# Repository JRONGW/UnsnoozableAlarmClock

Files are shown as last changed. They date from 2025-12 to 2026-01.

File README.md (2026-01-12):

# Unsnoozable Alarm Clock

Alarmclockcutouttop
ufocutout
topbottom

- The unsnoozable alarm clock uses a radar sensor to detect if a person is lying on the bed.
- It rings the alarm when alarm clock reaches and the person is present.
- It would not stop until the person leave the bed.

- An improved version is that the pressure pad is added to detect if the person is lying, so the pressure pad is pressed.
- If the pressure pad is pressed or the person is deteted by the radar, the alarm would keep ringing. Otherwise, it would stop ringing (person not detected by radar and the pad is not pressed).

### Instruction for users
- Set the time with the 3 buttons: set, up, and down. 'Set' button would change the set mode from real time hour, real time minute, alarm time hour, alarm time minute, and alarm on or off. In the final version, pressing the 'Set' button can lead you to the real time setting, with another long press to confirm the setting. The continuous hitting of 'Up' or 'Down' button can change the number continuously without re-hitting once a time.

- The pressure pad is separated from the clock, it will detect the pressure on pressure pad and send the status pressed/releaesed to MQTT.

- The pressure pad status can be obtained by the alarm clock and be a condition of the alarm.

- The alarm clock and the pressure pad part are powered by 5v adaptors.

# Iteration 1
iteration1withonlybuzzer

# Iteration 2
iteration2withonlymp3player

# Video of Progress

- Radar Person Detect:


- https://www.youtube.com/watch?v=DdHfjPsBJfA

- Pressue pad:



- https://www.youtube.com/shorts/LzBAYvfItaQ

# Circuit Progress

insideufo6

# Final Iteration
screenshotufo
[https://youtu.be/rHgdz_P1Rgc](https://www.youtube.com/watch?v=OdzALBfLdlw)

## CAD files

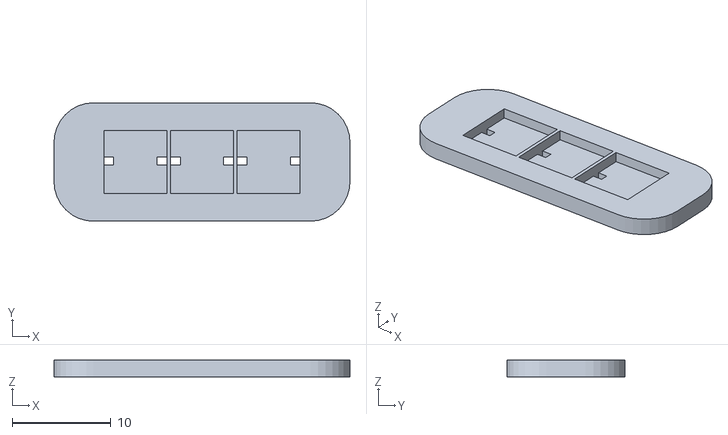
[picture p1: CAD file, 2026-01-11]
Design files/button back.stl
30.0 x 12.0 x 1.70

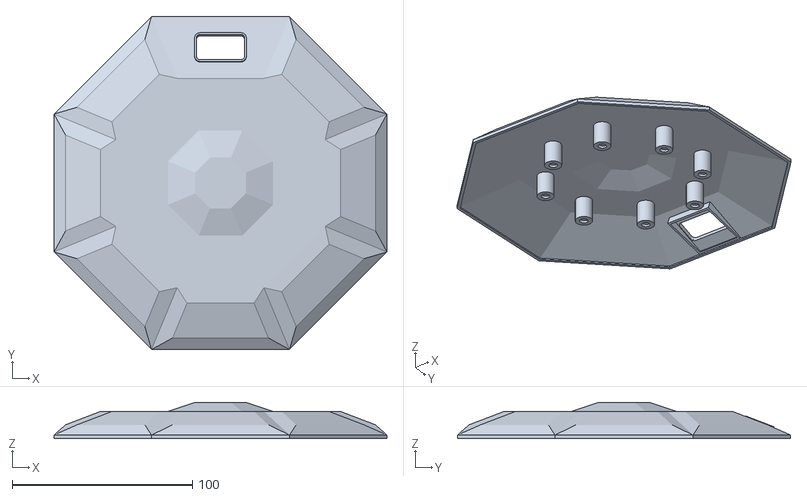
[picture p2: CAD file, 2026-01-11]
Design files/ufo lid.stl
184.8 x 184.8 x 20.1

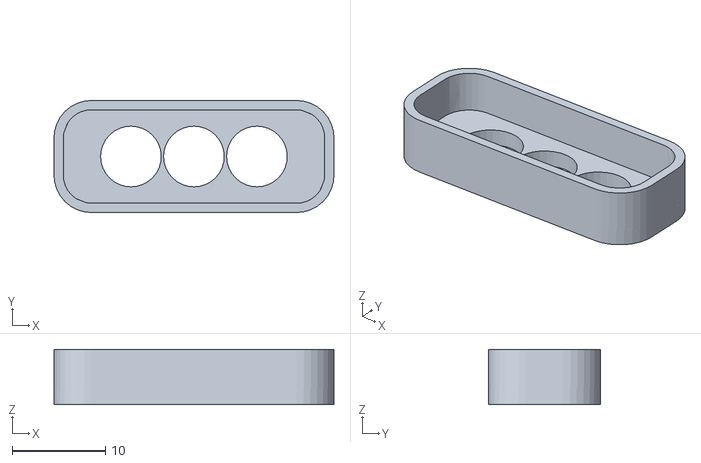
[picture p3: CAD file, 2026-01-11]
Design files/button box.stl
30.0 x 12.0 x 5.90

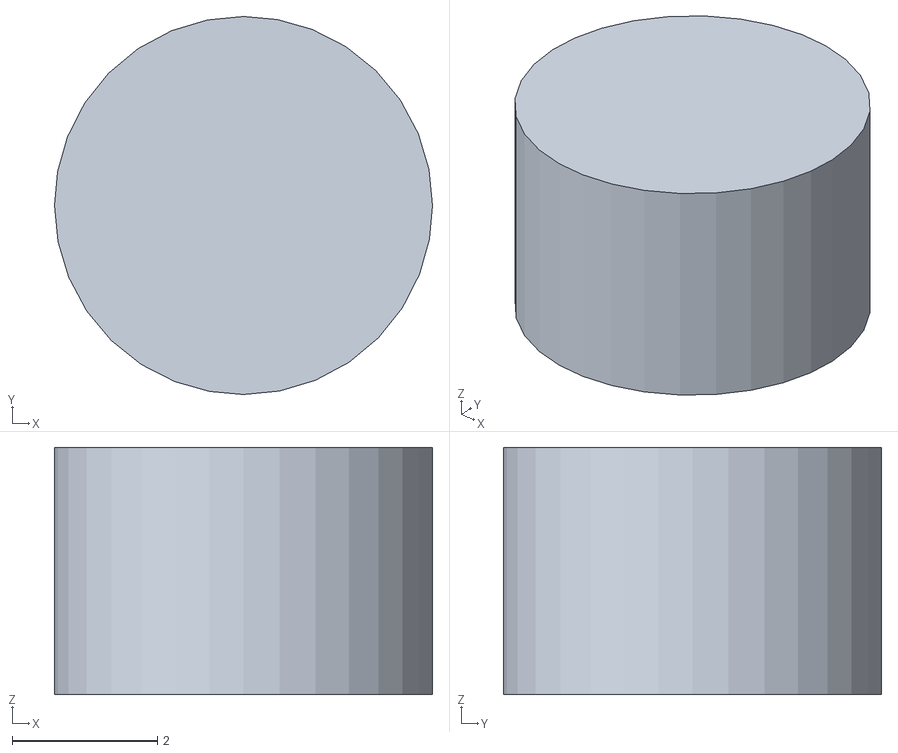
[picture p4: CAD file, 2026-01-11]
Design files/button large.stl
5.20 x 5.20 x 3.40

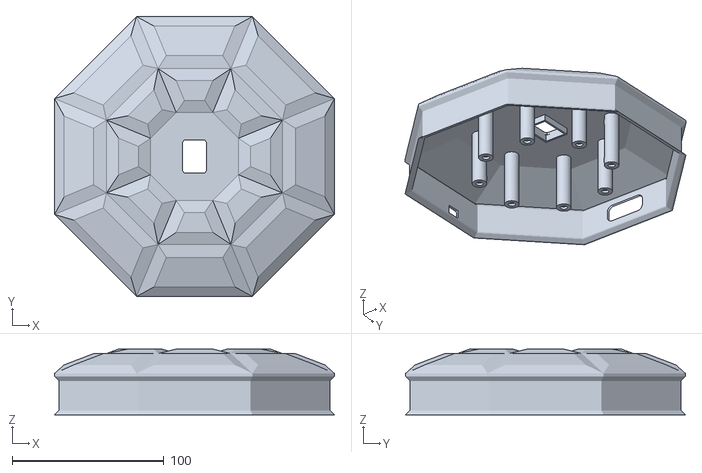
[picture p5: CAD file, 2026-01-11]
Design files/ufo bottom.stl
184.8 x 184.8 x 43.5

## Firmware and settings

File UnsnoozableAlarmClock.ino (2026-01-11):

// On 2026-01-07 at 17:16:10, the setting key was modified. Long press to enter the time modification, and short press to enter the alarm time modification.
// Configured for ESP32 DevKit V1 (WROOM-32)
#ifndef CONFIG_IDF_TARGET
#define CONFIG_IDF_TARGET "esp32"  
#endif

// DS1302 RTC Module:
//   VCC → ESP32 5V (or 3.3V)
//   GND → ESP32 GND
//   CLK → ESP32 GPIO18
//   DAT → ESP32 GPIO23
//   RST → ESP32 GPIO5
// DFPlayer Mini Connections:
//   VCC → ESP32 5V
//   GND → ESP32 GND  
//   TX → ESP32 GPIO2 (MP3_RX_PIN)
//   RX → ESP32 GPIO4 (MP3_TX_PIN)
//   SPK_1 → Speaker Red (+)   
//   SPK_2 → Speaker Black (-) 

#if defined(ESP32)
  #ifdef ESP_IDF_VERSION_MAJOR // IDF 4+
    #if CONFIG_IDF_TARGET_ESP32 // ESP32/PICO-D4
      #define MONITOR_SERIAL Serial
      #define RADAR_SERIAL Serial1
      #define RADAR_RX_PIN 33
      #define RADAR_TX_PIN 32
      MONITOR_SERIAL.print("CONFIG_IxDF_TARGET_ESP32");
   
    #elif CONFIG_IDF_TARGET_ESP32S2
      #define MONITOR_SERIAL Serial
      #define RADAR_SERIAL Serial1
      #define RADAR_RX_PIN 9
      #define RADAR_TX_PIN 8
    #elif CONFIG_IDF_TARGET_ESP32C3
      #define MONITOR_SERIAL Serial
      #define RADAR_SERIAL Serial1
      #define RADAR_RX_PIN 4
      #define RADAR_TX_PIN 5
    #else 
      #error Target CONFIG_IDF_TARGET is not supported
    #endif
  #else // ESP32 Before IDF 4.0
    #define MONITOR_SERIAL Serial
    #define RADAR_SERIAL Serial1
    #define RADAR_RX_PIN 33   //The RX1 pin of the ESP32 is connected to the TX pin of the radar
    #define RADAR_TX_PIN 32   //ESP32's TX1 is connected to the RX of the radar
  #endif
#elif defined(__AVR_ATmega32U4__)
  #define MONITOR_SERIAL Serial
  #define RADAR_SERIAL Serial1
  #define RADAR_RX_PIN 0
  #define RADAR_TX_PIN 1
#endif

#include <Arduino.h>
#include <WiFi.h>
#include <Wire.h>
#include <U8g2lib.h>
#include <ld2410.h>
#include <DFRobotDFPlayerMini.h>
#include <PubSubClient.h>
#include <ThreeWire.h>
#include <RtcDS1302.h>
#include "arduino_secrets.h"

/********* WIFI *********/
const char* ssid = SECRET_SSID;
const char* pass = SECRET_PASS;

/********* MQTT *********/
static const char* MQTT_HOST = "mqtt.cetools.org";
static const int   MQTT_PORT = 1884;  
static const char* MQTT_CLIENTID = "ALARM_CLOCK_JRONG_ESP32";
const char* mqtt_topic_subscribe = "student/CASA0019/Junrong/pressurepad";

/********* MQTT Authentication *********/
static const char* MQTT_USER = MQTT_USERNAME;
static const char* MQTT_PASS = MQTT_PASSWORD;

WiFiClient wifiClient;
PubSubClient mqtt(wifiClient);

// DS1302 RTC pins
#define RTC_CLK_PIN 18
#define RTC_DAT_PIN 23
#define RTC_RST_PIN 5

#define MP3_RX_PIN 4    //The RX2 pin of the ESP32 is connected to the TX pin of the MP3 (pin 3)
#define MP3_TX_PIN 2    //The TX2 pin of the ESP32 is connected to the RX pin (PIN2) of the MP3.

DFRobotDFPlayerMini mp3;
bool mp3Ready = false;

// Initialize DS1302
ThreeWire myWire(RTC_DAT_PIN, RTC_CLK_PIN, RTC_RST_PIN);
RtcDS1302<ThreeWire> rtc(myWire);

// U8g2 Constructor for ELEGOO 0.96" OLED (128x64, I2C) (ROTATE RESET SCL=22 SDA=21)
U8G2_SSD1306_128X64_NONAME_F_HW_I2C u8g2(U8G2_R0, U8X8_PIN_NONE, 22, 21);

// Button pins
#define BTN_SET 25  // Setting key: Switches menu options
#define BTN_UP 26   // Increase button: Click +1 / Long press for combo attack
#define BTN_DOWN 27 // Reduce key: Click -1 / Long press for combo attack

// Buzzer pin
#define BUZZER_PIN 13

// Button debounce
#define DEBOUNCE_DELAY 50
unsigned long lastDebounceTime[3] = {0, 0, 0};
bool lastButtonState[3] = {HIGH, HIGH, HIGH};
bool buttonState[3] = {HIGH, HIGH, HIGH};

// Pressure pad state (received via MQTT)
bool pressurePadPressed = false;
unsigned long lastPressureUpdate = 0;

// Menu states
enum MenuState {
  MENU_CLOCK,
  MENU_SET_HOUR,
  MENU_SET_MINUTE,
  MENU_SET_ALARM_HOUR,
  MENU_SET_ALARM_MINUTE,
  MENU_ALARM_ENABLE
};

MenuState currentMenu = MENU_CLOCK;

// Time variables
int currentHour = 12;
int currentMinute = 0;
int currentSecond = 0;
unsigned long lastTimeUpdate = 0;

// Alarm variables
int alarmHour = 7;
int alarmMinute = 0;
bool alarmEnabled = false;
bool alarmTriggered = false;
bool alarmRinging = false;

ld2410 radar;
uint32_t lastReading = 0;
bool radarConnected = false;
bool presenceDetected = false;
int targetDistance = 0;

bool displayConnected = false;
bool rtcConnected = false;
bool wifiConnected = false;
bool mqttConnected = false;

unsigned long lastMQTTAttempt = 0;
const unsigned long MQTT_RETRY_INTERVAL = 5000;

bool setting_mode = false;      //Set mode flag (true = enter settings / false = normal display)

// Button shake reduction + combo parameters (industrial-grade configuration, no need for modification)
const int DEBOUNCE_TIME = 20;   // Shake-off time: 20 ms
const int LONG_PRESS_TIME = 500;// Long press to determine time: 500ms
const int REPEAT_INTERVAL = 200;// The interval between consecutive attacks is 200 milliseconds.


// 将设置参数写入DS1302，立即生效
void saveParamToRtc() {
  RtcDateTime initTime(2026, 1, 3, 9, 35, 0); // Year, month, day, hour, minute, second
  rtc.SetDateTime(initTime);
}

// ==================== MQTT Callback ====================
void mqttCallback(char* topic, byte* payload, unsigned int length) {
  String message = "";
  for (int i = 0; i < length; i++) {
    message += (char)payload[i];
  }
  
  MONITOR_SERIAL.print("📩 MQTT [");
  MONITOR_SERIAL.print(topic);
  MONITOR_SERIAL.print("]: ");
  MONITOR_SERIAL.println(message);
  
  // Check if it's from the pressure pad topic
  if (String(topic) == mqtt_topic_subscribe) {
    if (message == "pressed") {
      pressurePadPressed = true;
      lastPressureUpdate = millis();
      MONITOR_SERIAL.println("✓ Pressure pad: PRESSED");
    } else if (message == "released") {
      pressurePadPressed = false;
      lastPressureUpdate = millis();
      MONITOR_SERIAL.println("✓ Pressure pad: RELEASED");
    }
  }
}

// ==================== WiFi Setup ====================
void connectWiFi() {
  if (WiFi.status() == WL_CONNECTED) return;
  
  MONITOR_SERIAL.print("Connecting to WiFi: ");
  MONITOR_SERIAL.println(ssid);
  
  u8g2.clearBuffer();
  u8g2.setFont(u8g2_font_6x10_tr);

  u8g2.setFont(u8g2_font_unifont_t_symbols); 
  u8g2.setFont(u8g2_font_open_iconic_all_1x_t); 
  u8g2.setFont(u8g2_font_7x13_t_symbols); 
  u8g2.drawStr(0, 15, "Connecting WiFi...");
  u8g2.sendBuffer();
  
  WiFi.begin(ssid, pass);
  
  int attempts = 0;
  while (WiFi.status() != WL_CONNECTED && attempts < 40) {
    delay(500);
    MONITOR_SERIAL.print(".");
    attempts++;
  }
  
  if (WiFi.status() == WL_CONNECTED) {
    wifiConnected = true;
    MONITOR_SERIAL.println("\n✓ WiFi Connected!");
    MONITOR_SERIAL.print("IP: ");
    MONITOR_SERIAL.println(WiFi.localIP());
    
    u8g2.clearBuffer();
    u8g2.setFont(u8g2_font_6x10_tr);
    u8g2.drawStr(0, 15, "WiFi Connected!");
    u8g2.sendBuffer();
    delay(2000);
  } else {
    wifiConnected = false;
    MONITOR_SERIAL.println("\n✗ WiFi Failed!");
    u8g2.clearBuffer();
    u8g2.setFont(u8g2_font_6x10_tr);
    u8g2.drawStr(0, 15, "WiFi Failed!");
    u8g2.sendBuffer();
    delay(2000);
  }
}

// ==================== MQTT Setup ====================
void ensureMQTT() {
  if (mqtt.connected()) {
    mqttConnected = true;
    return;
  }
  
  if (millis() - lastMQTTAttempt < MQTT_RETRY_INTERVAL) return;
  
  lastMQTTAttempt = millis();
  
  MONITOR_SERIAL.print("MQTT connect ");
  MONITOR_SERIAL.print(MQTT_HOST);
  MONITOR_SERIAL.print(":");
  MONITOR_SERIAL.println(MQTT_PORT);
  
  u8g2.clearBuffer();
  u8g2.setFont(u8g2_font_6x10_tr);
  u8g2.drawStr(0, 15, "Connecting MQTT...");
  u8g2.sendBuffer();
  
  bool ok = mqtt.connect(MQTT_CLIENTID, MQTT_USER, MQTT_PASS);
  
  if (ok) {
    mqttConnected = true;
    MONITOR_SERIAL.println("✓ MQTT Connected!");
    
    // Subscribe to pressure pad topic
    mqtt.subscribe(mqtt_topic_subscribe);
    MONITOR_SERIAL.print("Subscribed to: ");
    MONITOR_SERIAL.println(mqtt_topic_subscribe);
    
    u8g2.clearBuffer();
    u8g2.setFont(u8g2_font_6x10_tr);
    u8g2.drawStr(0, 15, "MQTT Connected!");
    u8g2.sendBuffer();
    delay(1000);
    
  } else {
    mqttConnected = false;
    MONITOR_SERIAL.print("MQTT fail rc=");
    MONITOR_SERIAL.println(mqtt.state());
    
    u8g2.clearBuffer();
    u8g2.setFont(u8g2_font_6x10_tr);
    u8g2.drawStr(0, 15, "MQTT Failed!");
    u8g2.sendBuffer();
  }
}
// 补零函数（格式化时间）
String formatNum(int num) {
  return num < 10 ? "0" + String(num) : String(num);
}

void setup(void)
{
  MONITOR_SERIAL.begin(115200);
  delay(1000);
  MONITOR_SERIAL.println("\n--- Un-Snoozeable Alarm Clock ---");
  
  // Setup buttons
  pinMode(BTN_SET, INPUT_PULLUP);
  pinMode(BTN_UP, INPUT_PULLUP);
  pinMode(BTN_DOWN, INPUT_PULLUP);

  // Setup buzzer
  pinMode(BUZZER_PIN, OUTPUT);
  digitalWrite(BUZZER_PIN, LOW);

  MONITOR_SERIAL.println("Initializing I2C for OLED...");
  Wire.begin(21, 22); // I2C initialization: SDA connected to 21, SCL connected to 22. For the other ESP32 I2C initialization, Wire.begin(18, 19);
  Wire.setClock(400000); // Increase the I2C speed to 400kHz (default is 100kHz)
  
  MONITOR_SERIAL.println("Initializing OLED Display...");

  // Initialize display
  u8g2.begin();
  u8g2.enableUTF8Print();
  displayConnected = true;
  
  MONITOR_SERIAL.println("Display initialized!");
  
  // Welcome screen
  u8g2.clearBuffer();
  u8g2.setFont(u8g2_font_ncenB14_tr);
  u8g2.drawStr(0, 20, "HELLO!");
  u8g2.setFont(u8g2_font_6x10_tr);
  u8g2.drawStr(0, 35, "Alarm Clock");
  u8g2.drawStr(0, 50, "Init systems...");
  u8g2.sendBuffer();
  
  delay(1000);

  // Initialize WiFi
  connectWiFi();
  
  // Initialize MQTT
  if (wifiConnected) {
    mqtt.setServer(MQTT_HOST, MQTT_PORT);
    mqtt.setCallback(mqttCallback);
    ensureMQTT();
  }

  // Initialize DS1302 RTC
  MONITOR_SERIAL.println("Initializing RTC Module...");
  MONITOR_SERIAL.print("  CLK: GPIO");
  MONITOR_SERIAL.println(RTC_CLK_PIN);
  MONITOR_SERIAL.print("  DAT: GPIO");
  MONITOR_SERIAL.println(RTC_DAT_PIN);
  MONITOR_SERIAL.print("  RST: GPIO");
  MONITOR_SERIAL.println(RTC_RST_PIN);
  
  rtc.Begin();
   // First use: Set the initial time
  RtcDateTime initTime(2026, 1, 3, 9, 35, 0); 
  if (!rtc.IsDateTimeValid()) {
    rtc.SetDateTime(initTime);
  	Serial.println("MH-DS1302 V2：Initialization time successful");
  } else {
     Serial.println("MH-DS1302 V2：The time is valid and does not need to be reset.");
  }

  if (!rtc.GetIsRunning()) {
    MONITOR_SERIAL.println("RTC was not running, starting now");
    rtc.SetIsRunning(true);
  }

  RtcDateTime now = rtc.GetDateTime();
  now = rtc.GetDateTime(); // Second reading, stable V2 version data
  rtcConnected = true;
  // Format the time
  static String date = String(now.Year()) + "/" + formatNum(now.Month()) + "/" + formatNum(now.Day());
  static String time = formatNum(now.Hour()) + ":" + formatNum(now.Minute()) + ":" + formatNum(now.Second());

  currentHour = now.Hour();
  currentMinute = now.Minute();
  currentSecond = now.Second();
  MONITOR_SERIAL.print(date);
  MONITOR_SERIAL.print(" Current RTC time: ");
  MONITOR_SERIAL.print(time);
  MONITOR_SERIAL.println(" ");  
  u8g2.clearBuffer();
  u8g2.setFont(u8g2_font_ncenB10_tr);
  u8g2.drawStr(0, 15, "Clock on!");
  u8g2.setFont(u8g2_font_6x10_tr);
  char timeStr[20];
  sprintf(timeStr, "Time: %02d:%02d:%02d", currentHour, currentMinute, currentSecond);
  u8g2.drawStr(0, 35, timeStr);
  u8g2.sendBuffer();
  delay(2000);

  // ---------- Initialize Radar ----------
  u8g2.clearBuffer();
  u8g2.setFont(u8g2_font_6x10_tr);
  u8g2.drawStr(0, 15, "Starting Radar...");
  u8g2.sendBuffer();

#if defined(ESP32)
  MONITOR_SERIAL.println("Initializing Radar UART...");
  MONITOR_SERIAL.printf("RADAR_RX_PIN=%d,RADAR_TX_PIN=%d  ", RADAR_RX_PIN, RADAR_TX_PIN);
  RADAR_SERIAL.begin(256000, SERIAL_8N1, RADAR_RX_PIN, RADAR_TX_PIN);
#elif defined(__AVR_ATmega32U4__)
  RADAR_SERIAL.begin(256000);
#endif

  delay(500);

  bool ok = false;
  unsigned long start = millis();

  while (millis() - start < 3000) {
    if (!ok) {
      MONITOR_SERIAL.println("Calling radar.begin()...");
      ok = radar.begin(RADAR_SERIAL);
    }

    radar.read();

    if (radar.isConnected()) {
      ok = true;
      break;
    }

    delay(100);
  }

  radarConnected = ok;

  u8g2.clearBuffer();
  u8g2.setFont(u8g2_font_6x10_tr);

  if (radarConnected) {
    MONITOR_SERIAL.println(F("Radar: OK"));

    u8g2.setFont(u8g2_font_ncenB10_tr);
    u8g2.drawStr(0, 15, "RADAR OK!");
    u8g2.setFont(u8g2_font_6x10_tr);

    char fwStr[20];
    sprintf(fwStr, "FW v%d.%d.%02X",
            radar.firmware_major_version,
            radar.firmware_minor_version,
            radar.firmware_bugfix_version);
    u8g2.drawStr(0, 30, fwStr);
  } else {
    MONITOR_SERIAL.println(F("Radar: FAILED"));

    u8g2.drawStr(0, 15, "Radar Error");
    u8g2.drawStr(0, 30, "Check wiring / reboot");
  }

  u8g2.sendBuffer();
  delay(2000);

  // --- Initialize MP3 player ---
  MONITOR_SERIAL.println("Initializing MP3 player...");
  MONITOR_SERIAL.print("  RX: GPIO");
  MONITOR_SERIAL.println(MP3_RX_PIN);
  MONITOR_SERIAL.print("  TX: GPIO");
  MONITOR_SERIAL.println(MP3_TX_PIN);

  Serial2.begin(9600, SERIAL_8N1, MP3_RX_PIN, MP3_TX_PIN);
  delay(2000);

  MONITOR_SERIAL.println("Attempting connection...");

  if (mp3.begin(Serial2)) {
    mp3Ready = true;
    MONITOR_SERIAL.println("✓ MP3 player OK");
    
    delay(500);
    mp3.volume(15);
    delay(500);
    
    // Test play
    MONITOR_SERIAL.println("Testing playback...");
    mp3.play(1);
    delay(3000);
    mp3.stop();
    
  } else {
    mp3Ready = false;
    MONITOR_SERIAL.println("❌ MP3 player NOT found");
    MONITOR_SERIAL.println("Check:");
    MONITOR_SERIAL.println("  - SD card inserted?");
    MONITOR_SERIAL.println("  - 0001.mp3 exists?");
    MONITOR_SERIAL.println("  - Wiring correct?");
    MONITOR_SERIAL.println("  - Power supply adequate (5V 2A)?");
  }

  // Show result on display
  u8g2.clearBuffer();
  u8g2.setFont(u8g2_font_6x10_tr);
  if (mp3Ready) {
    u8g2.drawStr(0, 15, "MP3: OK");
  } else {
    u8g2.drawStr(0, 15, "MP3: FAILED");
    u8g2.drawStr(0, 30, "Check Power/SD");
  }
  u8g2.sendBuffer();
  delay(2000);

  lastTimeUpdate = millis();
  
  MONITOR_SERIAL.println("\n=== SYSTEM READY ===");
  MONITOR_SERIAL.print("Display: ");
  MONITOR_SERIAL.println(displayConnected ? "OK" : "FAIL");
  MONITOR_SERIAL.print("RTC: ");
  MONITOR_SERIAL.println(rtcConnected ? "OK" : "FAIL");
  MONITOR_SERIAL.print("Radar: ");
  MONITOR_SERIAL.println(radarConnected ? "OK" : "FAIL");
  MONITOR_SERIAL.print("WiFi: ");
  MONITOR_SERIAL.println(wifiConnected ? "OK" : "FAIL");
  MONITOR_SERIAL.print("MQTT: ");
  MONITOR_SERIAL.println(mqttConnected ? "OK" : "FAIL");
  MONITOR_SERIAL.print("MP3: ");
  MONITOR_SERIAL.println(mp3Ready ? "OK" : "FAIL");
}

bool isButtonPressed(int buttonIndex, int buttonPin)
{
  bool reading = digitalRead(buttonPin);
  
  if (reading != lastButtonState[buttonIndex]) {
    lastDebounceTime[buttonIndex] = millis();
  }
  
  if ((millis() - lastDebounceTime[buttonIndex]) > DEBOUNCE_DELAY) {
    if (reading != buttonState[buttonIndex]) {
      buttonState[buttonIndex] = reading;
      
      if (buttonState[buttonIndex] == LOW) {
        lastButtonState[buttonIndex] = reading;
        return true;
      }
    }
  }
  
  lastButtonState[buttonIndex] = reading;
  return false;
}

void updateTime()
{
  if (millis() - lastTimeUpdate >= 1000) {
    lastTimeUpdate += 1000;

    if (rtcConnected && currentMenu == MENU_CLOCK) {
      // Normal mode: follow RTC
      RtcDateTime now = rtc.GetDateTime();
      now = rtc.GetDateTime();
      currentHour   = now.Hour();
      currentMinute = now.Minute();
      currentSecond = now.Second();
    } else {
      // In setting menus (or no RTC): let time tick locally
      currentSecond++;
      if (currentSecond >= 60) {
        currentSecond = 0;
        currentMinute++;
        if (currentMinute >= 60) {
          currentMinute = 0;
          currentHour = (currentHour + 1) % 24;
        }
      }
    }

    // Check alarm every second
    // Previously, the alarm was triggered when the time was exactly at "whole hours, whole minutes, and seconds equal to 0" (for example, if the alarm was set for 8:30, it would be triggered at 8:30:00). However, directly using this condition has three major issues: inaccurate triggering, missed triggering, and repeated triggering.
    // 1. Basic condition: Hours and minutes match (seconds are relaxed to 0-2, tolerating time synchronization/loop delay)
   bool timeMatch = (currentHour == alarmHour) && (currentMinute == alarmMinute) && (currentSecond >= 0 && currentSecond <= 2);
  // 2. Trigger condition: Time match + No trigger within this minute
  if (alarmEnabled && timeMatch && !alarmTriggered) {
  //   triggerAlarm(); // Execute the alarm logic (ringing / radar alert / sending MQTT, etc.)
    MONITOR_SERIAL.println("⏰ ALARM TRIGGERED!");
    alarmTriggered = true; // Mark as triggered to avoid repetition
  }

  // 3. Reset marker: After a minute change, it is allowed to trigger again (for example, from 8:30 → 8:31, reset the marker)
  if (currentMinute != alarmMinute) {
//    alarmTriggered = false;
  }

  }
}

void checkAlarm()
{
  // Alarm rings when BOTH conditions are met:
  // 1. Alarm is triggered (time reached)
  // 2. Person detected by radar OR pressure pad is pressed
  bool personDetected = (presenceDetected && targetDistance < 100) || pressurePadPressed;
  
  if (alarmTriggered && personDetected) {
    if (!alarmRinging) {
      MONITOR_SERIAL.println("🔊 ALARM RINGING - PERSON DETECTED!");
      if (pressurePadPressed) {
        MONITOR_SERIAL.println("   └─ Via pressure pad");
      }
      if (presenceDetected) {
        MONITOR_SERIAL.println("   └─ Via radar");
      }
     
      
      // Play MP3 track
      if (mp3Ready && !alarmRinging) {
        mp3.play(1);          // Play the specified track first
        delay(50);              // Wait for the playback command to take effect (short delay, non-blocking alternative available)
        mp3.volume(30);
        mp3.loop(1);  // Play first track on repeat
        alarmRinging = true;
      }

     }
    tone(BUZZER_PIN, 4000, 200);  // Keep buzzer as backup
  } else {
    if (alarmRinging) {
      alarmRinging = false;
      alarmTriggered = false;
      noTone(BUZZER_PIN);
      
  // 4. 停止循环播放
      // Stop MP3 playback
      if (mp3Ready) {
        mp3.stop();             
        mp3.loop(0);            // cancel loop
        alarmRinging = false;
      }
    }
  }
  
  // // Reset alarm after the minute passes
  // if (alarmTriggered && currentSecond == 0 && currentMinute != alarmMinute) {
  //   alarmTriggered = false;
  //   alarmRinging = false;
  //   if (mp3Ready) mp3.stop();
  //   MONITOR_SERIAL.println("Alarm reset");
  // }
}
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
void loop()
{
  // Maintain WiFi connection
  if (WiFi.status() != WL_CONNECTED) {
    connectWiFi();
  }
  
  // Maintain MQTT connection
  ensureMQTT();
  
  // Process MQTT messages
  mqtt.loop();
  
  updateTime();
  radar.read(); // First, trigger the reception of the underlying data from the radar (for some radars, the read() function needs to be called first before the status is checked)
  
  // Optimized radar data reading conditions
  unsigned long currentMillis = millis();
  // 1. First, determine the time interval (fixing overflow + sequence optimization), and then determine the radar connection.
  if ((currentMillis - lastReading >= 500) && radar.isConnected()) {
    // Immediately update the timing to avoid repeated reading caused by multi-threading or loop cycles.
    lastReading = currentMillis;
  //if (radar.isConnected() && millis() - lastReading > 500)
  //{
   // lastReading = millis();
    
   // Read the core data of the radar
    // Raw presence from radar
    bool rawPresence = radar.presenceDetected();
    int distance = 0;
     
      // Static target distance: Add validity verification (to avoid outliers)
    if (rawPresence)
    {
      if (radar.stationaryTargetDetected())
      {
        int stationaryDist = radar.stationaryTargetDistance();
        if (stationaryDist >= 0 && stationaryDist <= 500) { // Maximum detection range limit of radar
          distance = stationaryDist;
        }    
      }

        // Distance of moving target: Preferentially take the closer valid distance
      if (radar.movingTargetDetected())
      {
        int md = radar.movingTargetDistance();
        if (distance == 0 || md < distance) {
          distance = md;
        }
      }
    }

    targetDistance = distance;

    // Redefine "presenceDetected" to mean "person closer than 100cm"
    if (rawPresence && targetDistance > 0 && targetDistance < 100) {
      presenceDetected = true;
    } else {
      presenceDetected = false;
    }
  }

  handleButtons();
  checkAlarm();
  updateDisplay();
  
  delay(50);
}

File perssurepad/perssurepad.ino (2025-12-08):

#include <U8g2lib.h>
#include <Wire.h>
#include <WiFi.h>
#include <PubSubClient.h>
#include <arduino_secrets.h>
/********* WIFI *********/
char ssid[] = SECRET_SSID;
char pass[] = SECRET_PASS;

/********* MQTT *********/
static const char* MQTT_HOST = "mqtt.cetools.org";
static const int   MQTT_PORT = 1884;  
static const char* MQTT_CLIENTID = "PRESSURE_PAD_JRONG_ESP32";
const char* mqtt_topic = "student/CASA0019/Junrong/pressurepad";

/********* MQTT Authentication *********/
static const char* MQTT_USER = "student";
static const char* MQTT_PASS = "ce2021-mqtt-forget-whale";

/********* Hardware *********/
// ESP32 I2C pins: SDA=21, SCL=22 (default)
U8G2_SSD1306_128X64_NONAME_F_HW_I2C u8g2(U8G2_R0, U8X8_PIN_NONE, 22, 21);

const int MAT_PIN = 14;  // GPIO14 for pressure mat
const int LED_PIN = 2;   // ESP32 built-in LED

WiFiClient wifiClient;
PubSubClient mqtt(wifiClient);

bool matPressed = false;
bool lastMatPressed = false;

unsigned long lastConnectionAttempt = 0;
const unsigned long RECONNECT_INTERVAL_MS = 5000;

void setup() {
  Serial.begin(115200);  // ESP32 typically uses 115200
  delay(2000);
  
  pinMode(MAT_PIN, INPUT_PULLUP);
  pinMode(LED_PIN, OUTPUT);
  
  Serial.println("=== ESP32 Pressure Mat MQTT Publisher ===");
  
  // Initialize I2C for display
  Wire.begin(21, 22);  // SDA=21, SCL=22
  
  // Initialize display
  u8g2.begin();
  u8g2.enableUTF8Print();
  u8g2.clearBuffer();
  u8g2.setFont(u8g2_font_ncenB14_tr);
  u8g2.drawStr(0, 20, "HELLO!");
  u8g2.setFont(u8g2_font_6x10_tr);
  u8g2.drawStr(0, 35, "Pressure Sensor");
  u8g2.drawStr(0, 50, "ESP32 Version");
  u8g2.sendBuffer();
  delay(2000);
  
  // Connect to WiFi
  connectWiFi();
  
  // Setup MQTT
  mqtt.setServer(MQTT_HOST, MQTT_PORT);
  
  Serial.println("Setup complete!");
}

void connectWiFi() {
  // Early return if already connected
  if (WiFi.status() == WL_CONNECTED) return;
  
  Serial.print("Connecting to WiFi: ");
  Serial.println(ssid);
  
  u8g2.clearBuffer();
  u8g2.setFont(u8g2_font_6x10_tr);
  u8g2.drawStr(0, 15, "Connecting WiFi...");
  u8g2.sendBuffer();
  
  WiFi.begin(ssid, pass);
  
  int attempts = 0;
  while (WiFi.status() != WL_CONNECTED && attempts < 40) {
    delay(500);
    Serial.print(".");
    attempts++;
  }
  
  if (WiFi.status() == WL_CONNECTED) {
    Serial.println("\n✓ WiFi Connected!");
    Serial.print("IP: ");
    Serial.println(WiFi.localIP());
    
    u8g2.clearBuffer();
    u8g2.setFont(u8g2_font_6x10_tr);
    u8g2.drawStr(0, 15, "WiFi Connected!");
    
    char ipStr[20];
    sprintf(ipStr, "%d.%d.%d.%d", 
            WiFi.localIP()[0], 
            WiFi.localIP()[1], 
            WiFi.localIP()[2], 
            WiFi.localIP()[3]);
    u8g2.drawStr(0, 30, ipStr);
    u8g2.sendBuffer();
    delay(2000);
  } else {
    Serial.println("\n✗ WiFi Failed!");
    u8g2.clearBuffer();
    u8g2.setFont(u8g2_font_6x10_tr);
    u8g2.drawStr(0, 15, "WiFi Failed!");
    u8g2.sendBuffer();
    delay(2000);
  }
}

void ensureMQTT() {
  // Early return if already connected
  if (mqtt.connected()) return;
  
  // Don't try too often
  if (millis() - lastConnectionAttempt < RECONNECT_INTERVAL_MS) return;
  
  lastConnectionAttempt = millis();
  
  Serial.print("MQTT connect ");
  Serial.print(MQTT_HOST);
  Serial.print(":");
  Serial.println(MQTT_PORT);
  
  u8g2.clearBuffer();
  u8g2.setFont(u8g2_font_6x10_tr);
  u8g2.drawStr(0, 15, "Connecting MQTT...");
  u8g2.sendBuffer();
  
  // Connect WITH authentication
  bool ok = mqtt.connect(MQTT_CLIENTID, MQTT_USER, MQTT_PASS);
  
  if (ok) {
    Serial.println("✓ MQTT Connected!");
    Serial.print("Client ID: ");
    Serial.println(MQTT_CLIENTID);
    Serial.print("Topic: ");
    Serial.println(mqtt_topic);
    
    u8g2.clearBuffer();
    u8g2.setFont(u8g2_font_6x10_tr);
    u8g2.drawStr(0, 15, "MQTT Connected!");
    u8g2.sendBuffer();
    delay(1000);
    
    // Send initial state
    const char* initialState = matPressed ? "pressed" : "released";
    mqtt.publish(mqtt_topic, initialState, true);
    
    Serial.print("Initial state: ");
    Serial.println(initialState);
    
  } else {
    Serial.print("MQTT fail rc=");
    Serial.println(mqtt.state());
    
    u8g2.clearBuffer();
    u8g2.setFont(u8g2_font_6x10_tr);
    u8g2.drawStr(0, 15, "MQTT Failed!");
    char errorStr[20];
    sprintf(errorStr, "rc=%d", mqtt.state());
    u8g2.drawStr(0, 30, errorStr);
    u8g2.sendBuffer();
  }
}

void loop() {
  // Maintain WiFi connection
  if (WiFi.status() != WL_CONNECTED) {
    connectWiFi();
  }
  
  // Maintain MQTT connection (non-blocking)
  ensureMQTT();
  
  // Process MQTT messages
  mqtt.loop();
  
  // Read mat state
  matPressed = (digitalRead(MAT_PIN) == LOW);
  
  // Visual feedback (blink LED when pressed)
  digitalWrite(LED_PIN, matPressed ? HIGH : LOW);
  
  // Update display
  u8g2.clearBuffer();
  u8g2.setFont(u8g2_font_ncenB10_tr);
  u8g2.drawStr(0, 20, "Mat Status:");
  
  u8g2.setFont(u8g2_font_ncenB14_tr);
  if (matPressed) {
    u8g2.drawStr(10, 45, "PRESSED");
  } else {
    u8g2.drawStr(5, 45, "RELEASED");
  }
  
  // Show connection status
  u8g2.setFont(u8g2_font_6x10_tr);
  if (mqtt.connected()) {
    u8g2.drawStr(0, 63, "MQTT: OK");
  } else {
    u8g2.drawStr(0, 63, "MQTT: Connecting...");
  }
  
  u8g2.sendBuffer();
  
  // Publish only when state changes
  if (matPressed != lastMatPressed) {
    const char* status = matPressed ? "pressed" : "released";
    
    if (mqtt.publish(mqtt_topic, status, true)) {
      Serial.print("📤 Published: ");
      Serial.println(status);
    } else {
      Serial.println("❌ Publish failed");
    }
    
    lastMatPressed = matPressed;
  }
  
  delay(100);
}

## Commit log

2025-12-08 add pressurepad
2026-01-11 Update UnsnoozableAlarmClock.ino
    Update the button functions, adding grace time to alarm time
2026-01-11 Design files
    [button back.stl, button box.stl, button large.stl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]
